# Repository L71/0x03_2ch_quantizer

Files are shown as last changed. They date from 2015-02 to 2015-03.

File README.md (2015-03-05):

0x03 2ch Quantizer
==================

This thing is a two channel CV quantizer for Eurorack, intended to make sure
some oscillators played by an analog sequencer are actually playing in tune :)

* two CV input channels, each input 0-5V is mapped to output 0-4.096V, four octaves @ 1V/oct.
* transpose knob per channel, +/- 1 octave in semitone steps
* The green LEDs will be brighter when transpose is set to -12/0/+12 half notes
* Red LED lights up if any channel tries to go off limits

Prototype build for Eurorack (complete with panel) was OK :) 

The microcontroller source code is released under the GPL v3.0 license. 
The PCBs and front panel drawings are released under the Creative Commons CC-BY-SA 4.0 license.

Tools used, all on MacOS 10.10:
C compiler: avr-gcc 4.3.3, http://www.obdev.at/products/crosspack/index.html
PCB: Eagle 7.1, www.cadsoftusa.com
Panel: Inkscape 0.91, inkscape.org

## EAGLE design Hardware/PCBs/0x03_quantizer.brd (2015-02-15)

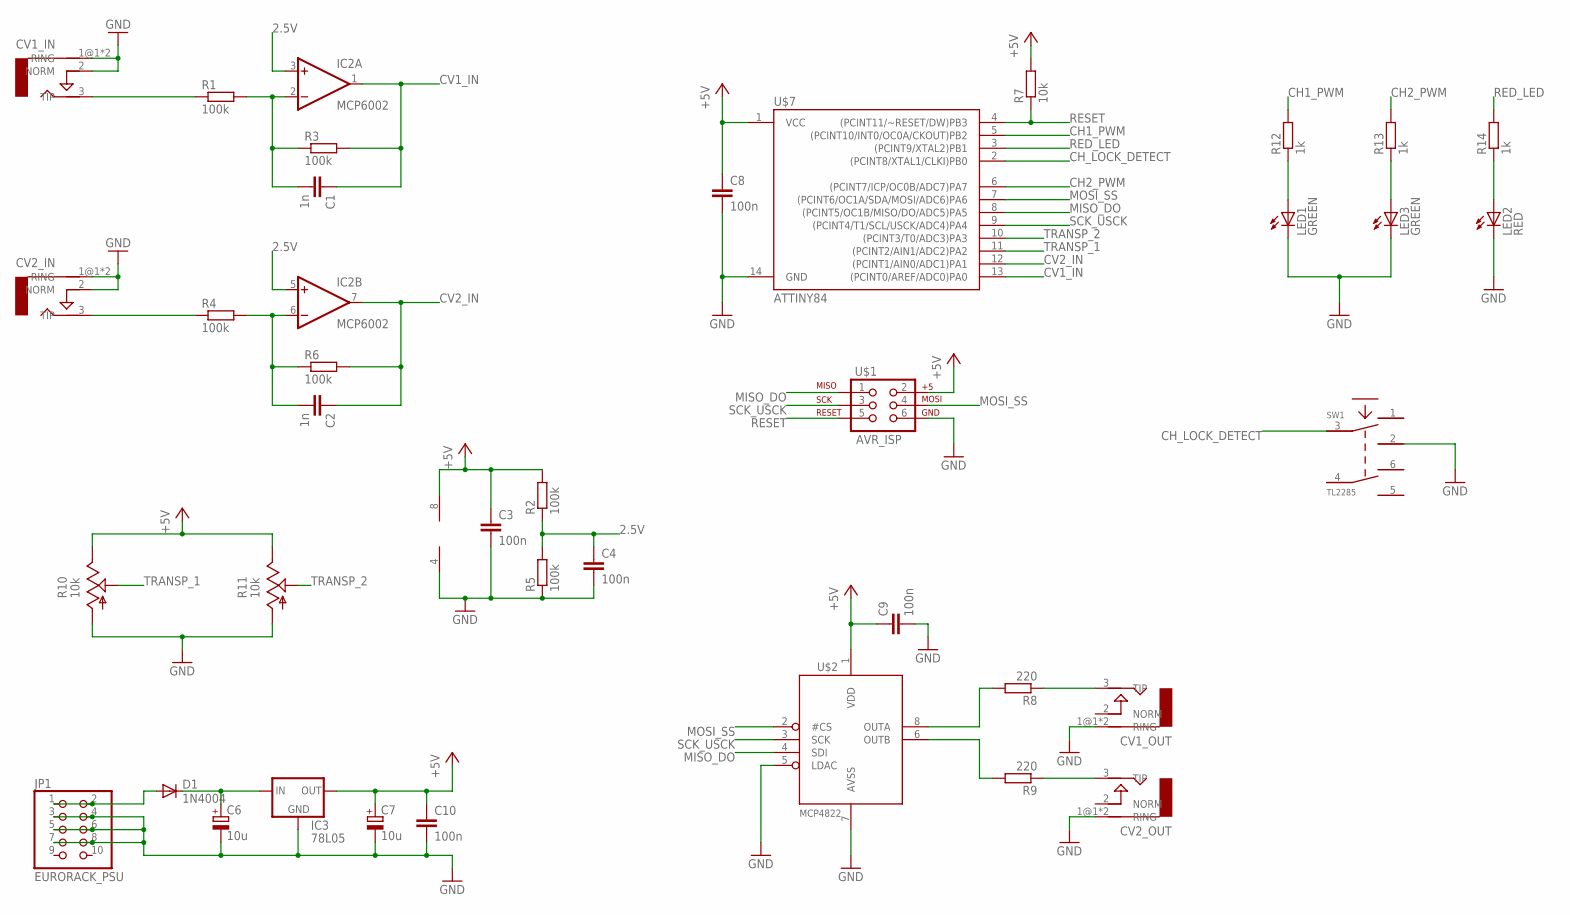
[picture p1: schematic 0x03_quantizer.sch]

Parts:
C1, C2: 1n; C025-025X050
C3, C4, C8, C9, C10: 100n; C025-025X050
C6, C7: 10u; E2,5-5
CV1_IN: CV1_IN; ERTHENVAR-JACK
CV1_OUT, CV2_OUT: AUDIO-JACKERTHENVAR; ERTHENVAR-JACK
CV2_IN: CV2_IN; ERTHENVAR-JACK
D1: 1N4004; DO41-10
IC2: MCP6002; DIL08
IC3: 78L05; 78LXX
JP1: EURORACK_PSU; 2X05
LED1, LED3: GREEN; LED5MM
LED2: RED; LED5MM
R1, R2, R3, R4, R5, R6: 100k; 0207/2V
R7: 10k; 0207/2V
R8, R9: 220; 0207/2V
R10, R11: 10k; ALPS_POT_VERTICAL
R12, R13, R14: 1k; 0207/2V
SW1: TL2285; TL2285_PCB
U$1: AVR_ISP; 2X3
U$2: MCP4822; DIL08
U$7: ATTINY84; DIL14

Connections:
2.5V: C4.1, IC2.3 (+IN), IC2.5 (+IN), R2.1, R5.2
12V: D1.A, JP1.1, JP1.2
+5V: C3.1, C7.+, C8.1, C9.1, C10.1, IC2.8 (V+), IC3.OUT, R2.2, R7.2, R10.P$1 (E), R11.P$1 (E), U$1.2, U$2.1 (VDD), U$7.1 (VCC)
AVSS: U$2.7 (AVSS)
CH1_PWM: R12.2, U$7.5 ((PCINT10/INT0/OC0A/CKOUT)PB2)
CH2_PWM: R13.2, U$7.6 ((PCINT7/ICP/OC0B/ADC7)PA7)
CH_LOCK_DETECT: SW1.3, U$7.2 ((PCINT8/XTAL1/CLKI)PB0)
CV1_IN: C1.1, IC2.1 (OUT), R3.2, U$7.13 ((PCINT0/AREF/ADC0)PA0)
CV2_IN: C2.1, IC2.7 (OUT), R6.2, U$7.12 ((PCINT1/AIN0/ADC1)PA1)
GND: C3.2, C4.2, C6.-, C7.-, C8.2, C9.2, C10.2, CV1_IN.1@1 (RING), CV1_IN.1@2 (RING), CV1_IN.2 (NORM), CV1_OUT.1@1 (RING), CV1_OUT.1@2 (RING), CV2_IN.1@1 (RING), CV2_IN.1@2 (RING), CV2_IN.2 (NORM), CV2_OUT.1@1 (RING), CV2_OUT.1@2 (RING), IC2.4 (V-), IC3.GND, JP1.3, JP1.4, JP1.5, JP1.6, JP1.7, JP1.8, LED1.K (C), LED2.K (C), LED3.K (C), R5.1, R10.P$3 (A), R11.P$3 (A), SW1.2, U$1.6, U$2.5 (LDAC), U$7.14 (GND)
MISO_DO: U$1.1, U$2.4 (SDI), U$7.8 ((PCINT5/OC1B/MISO/DO/ADC5)PA5)
MOSI_SS: U$1.4, U$2.2 (#CS), U$7.7 ((PCINT6/OC1A/SDA/MOSI/ADC6)PA6)
unnamed: C1.2, IC2.2 (-IN), R1.2, R3.1
unnamed: C6.+, D1.C, IC3.IN
unnamed: CV1_OUT.3 (TIP), R8.1
unnamed: CV1_IN.3 (TIP), R1.1
unnamed: CV2_OUT.3 (TIP), R9.1
unnamed: R9.2, U$2.6 (OUTB)
unnamed: C2.2, IC2.6 (-IN), R4.2, R6.1
unnamed: LED2.A, R14.1
unnamed: CV2_IN.3 (TIP), R4.1
unnamed: R8.2, U$2.8 (OUTA)
unnamed: LED3.A, R13.1
unnamed: LED1.A, R12.1
RED_LED: R14.2, U$7.3 ((PCINT9/XTAL2)PB1)
RESET: R7.1, U$1.5, U$7.4 ((PCINT11/~RESET/DW)PB3)
SCK_USCK: U$1.3, U$2.3 (SCK), U$7.9 ((PCINT4/T1/SCL/USCK/ADC4)PA4)
TRANSP_1: R10.P$2 (S), U$7.11 ((PCINT2/AIN1/ADC2)PA2)
TRANSP_2: R11.P$2 (S), U$7.10 ((PCINT3/T0/ADC3)PA3)

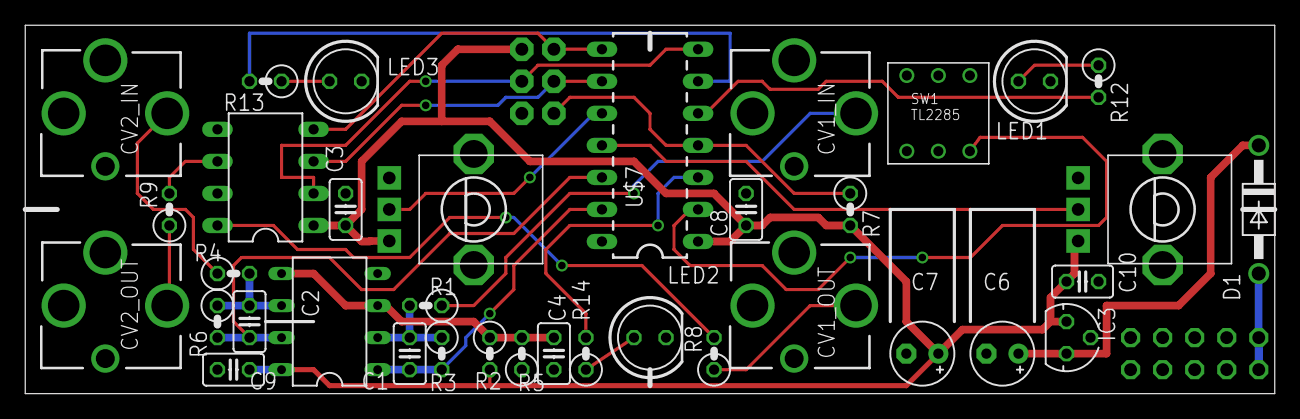
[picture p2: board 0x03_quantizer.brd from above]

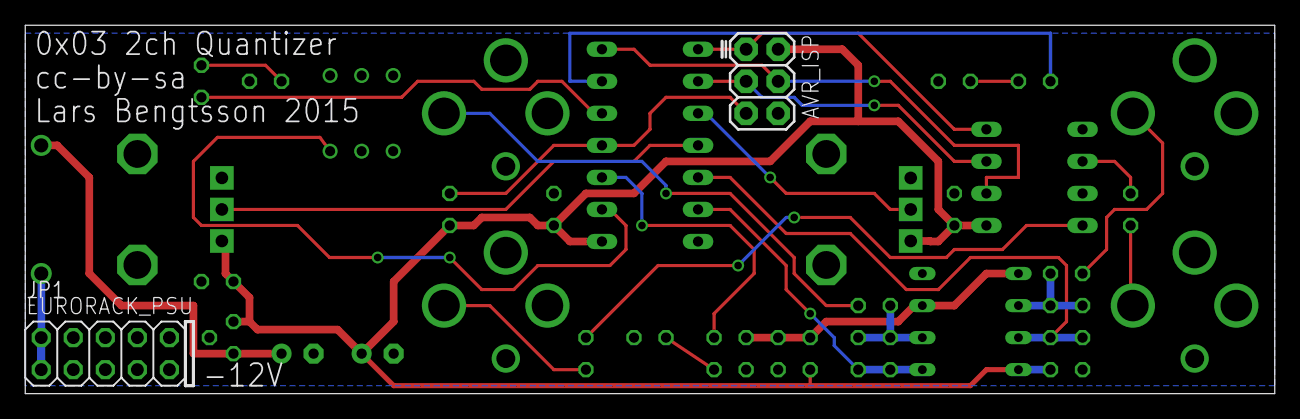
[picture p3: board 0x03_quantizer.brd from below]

Board: 2 copper layers, 99.1 x 29.2 mm, 38 parts (2 on the bottom side), 28 nets.

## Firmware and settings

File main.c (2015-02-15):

#define F_CPU 8000000UL

#include <avr/io.h>
#include <util/delay.h>
#include <avr/interrupt.h>

#include "adc.h"
#include "spi.h"
#include "ui.h"

int main() {

	
	// input pin @ PB0 detects channel lock with push switch (so activate pull-up)
	PORTB |= _BV(PB0);
	
	// initialize SPI
	setup_spi();
	
	// setup PWM outputs
	setup_pwm_outputs();
	
	// start AD conversions
	adc_setup();
    run_adc_timer();
	
    // Enable interrupts for all. GO! =)
    SREG |= 0x80 ;
	
	while (1) {
		_delay_ms(500);
		// PORTB = PORTB ^ 0b00000011;
		
	}
	
	
}

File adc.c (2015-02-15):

// ADC setup & data collection

#include <avr/io.h>
#include <avr/interrupt.h>

#include "spi.h"
#include "ui.h"

// ADC latest values
struct adc_data {
        int8_t cv1_in, cv1_transp, cv2_in, cv2_transp ;
} adc ;


void adc_setup() {
    // enable ADC, clock prescaler = /64
    ADCSRA |= (1<<ADEN) | (1<<ADPS2) | (1<<ADPS0) ;

    // left adjust result
    ADCSRB |= (1<<ADLAR);

    // disable digital IO on used ADC pins
    DIDR0 = 0b00001111;

    // Go! =)
    ADCSRA |= (1<<ADSC) ;
}

void run_adc_timer() {  // enable 16bit timer1 + interrupts

	OCR1AH = 0x07; // 8MHz, divider 2000 -> 4KHz timer -> update CVs @ 1000Hz
	OCR1AL = 0xd0;

    // OCR1AH = 0x03; // 8MHz, divider 1000 -> 8KHz timer
    // OCR1AL = 0xe8;

    // clear on OCR1A, clock prescaler 1.
    TCCR1B |= (1<<WGM12) | (1<<CS10) ;
    // TCCR1B |= (1<<WGM12) | (1<<CS10) | (1<<CS11) ;  // presc. /64

    // enable OCR1A interrupt
    TIMSK1 |= (1<<OCIE1A);
}

int8_t tr2key(uint8_t tr) {
	// convert transpose knob value to key +/-
	int8_t key=-13+(tr/10);
	if ( key <= -1 ) {
		key++;
	}
	return(key);
}
 
int8_t cv2key(uint8_t cv) {
	// convert CV input value (0-255) -> key number 0-49
	int8_t key=cv/5;
	if ( key > 49 ) {
		key = 49;
	}
	return(key);
}

uint16_t key2dacv(int8_t key) {
	// convert key number to DAC output value/voltage in mV
	return(((uint16_t)key*1000)/12);
}


int8_t process_channel_key(int8_t cvkey, int8_t trkey, uint8_t channel) {
	int8_t retkey=cvkey + trkey;
	PORTB &= ~_BV(PB1); // clear RED led
	if ( retkey < 0 ) {  // hit bottom? Return 0 and light RED!
		retkey = 0;
		PORTB |= _BV(PB1);
	}
	if ( retkey > 49 ) {  // above top value? Cut and light RED!
		retkey = 49;
		PORTB |= _BV(PB1);
	}
	return(retkey);
}

ISR(TIM1_COMPA_vect) {

    static uint8_t adc_chan=0;
    uint8_t chan_mask=0x03; // use 4 channels (0-3).
    uint8_t adc_in = ADCH;  // read input value & invert it.

	// read channel lock switch (pressed = 0)
	uint8_t locksw = PINB & _BV(PB0);
	
    switch (adc_chan) {
        case 0 :        // chan 0, CV1 input
           	adc.cv1_in = cv2key(255 - adc_in);
			spi_write_word_cha(key2dacv(process_channel_key(adc.cv1_in,adc.cv1_transp,1)));
			setleds(adc.cv1_in,adc.cv1_transp,1);
           	break;
        case 2 :        // chan 2, CV1 transpose knob
            adc.cv1_transp = tr2key(adc_in);
            break;
        case 1 :        // chan 1, CV2 input
            adc.cv2_in = cv2key(255 - adc_in);
			if (!locksw) { // if switch is pressed (locksw = 0), copy cv1 -> cv2.
				adc.cv2_in = adc.cv1_in;
			}
			spi_write_word_chb(key2dacv(process_channel_key(adc.cv2_in,adc.cv2_transp,2)));
			setleds(adc.cv2_in,adc.cv2_transp,2);
            break;
        case 3 :        // chan 3, CV2transpose knob
            adc.cv2_transp = tr2key(adc_in);
            break;
    }

    adc_chan = ((adc_chan+1) & chan_mask ) ;

    // update ADMUX register
    ADMUX &= 0xf0;  // reset channel bits
    ADMUX |= adc_chan ;

    // start next conversion
    ADCSRA |= (1<<ADSC) ;
	
}

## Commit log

2015-02-15 Initial upload of PCB files.
    [0x03_quantizer.brd, 0x03_quantizer.sch]
2015-02-19 Final version for first order (no LED holes, for transparent panel).
2015-02-27 Front panel file with 5mm holes for LEDs. Use for opaque panels.
2015-03-05 Updated after first prototype build.
2015-03-25 Updated: No fill in text, just outlines, and holes for 5mm LEDs.
2015-03-25 Missed to change one hole. Corrected.

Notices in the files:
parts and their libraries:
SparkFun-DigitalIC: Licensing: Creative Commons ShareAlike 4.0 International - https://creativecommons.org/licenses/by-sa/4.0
